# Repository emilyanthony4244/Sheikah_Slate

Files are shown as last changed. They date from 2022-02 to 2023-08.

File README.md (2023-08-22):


<!--
*** Thanks for checking out the Best-README-Template. If you have a suggestion
*** that would make this better, please fork the repo and create a pull request
*** or simply open an issue with the tag "enhancement".
*** Don't forget to give the project a star!
*** Thanks again! Now go create something AMAZING! :D
-->

<!-- PROJECT SHIELDS -->
<!--
*** I'm using markdown "reference style" links for readability.
*** Reference links are enclosed in brackets [ ] instead of parentheses ( ).
*** See the bottom of this document for the declaration of the reference variables
*** for contributors-url, forks-url, etc. This is an optional, concise syntax you may use.
*** https://www.markdownguide.org/basic-syntax/#reference-style-links
-->
[][contributors-url]
[][forks-url]
[][stars-url]
[][issues-url]
[][license-url]
[][linkedin-url]

<!-- PROJECT LOGO -->
<br />
<div align="center">
   


  <h3 align="center">Sheikah Slate Cosplay Project</h3>

  <p align="center">
    A functional, open source Sheikah Slate for cosplay or collectors.
<br />
    <a href="https://github.com/emilyanthony4244/Sheikah_Slate"><strong>Explore the slate »</strong></a>
<br />
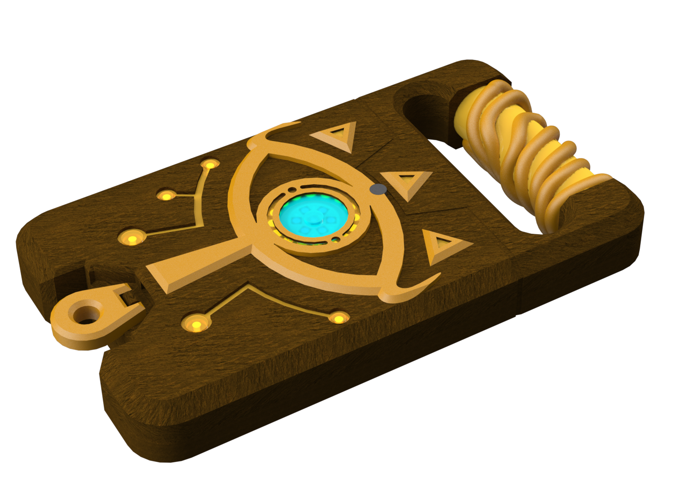
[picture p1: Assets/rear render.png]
rear render


<br />
    
<a href=" ">Demo Placeholder Link</a>
<br />

<a href="https://github.com/othneildrew/Best-README-Template/issues">Report Bug</a>

<a href="https://github.com/othneildrew/Best-README-Template/issues">Request Feature</a>
  </p>
</div>

<!-- TABLE OF CONTENTS -->
<details>
  <summary>Table of Contents</summary>
  <ol>
    <li>
      <a href="#about-the-project">About The Project</a>
      <ul>
        <li><a href="#built-with">Built With</a></li>
      </ul>
    </li>
    <li>
      <a href="#getting-started">Getting Started</a>
      <ul>
        <li><a href="#prerequisites">Prerequisites</a></li>
        <li><a href="#installation">Installation</a></li>
      </ul>
    </li>
    <li><a href="#usage">Usage</a></li>
    <li><a href="#roadmap">Roadmap</a></li>
    <li><a href="#contributing">Contributing</a></li>
    <li><a href="#license">License</a></li>
    <li><a href="#contact">Contact</a></li>
    <li><a href="#acknowledgments">Acknowledgments</a></li>
  </ol>
</details>

<!-- ABOUT THE PROJECT -->
## About The Project

In November 2021 I decided to tackle my next cosplay build – Nintendo’s Zelda Breath of the Wild’s Link, specifically his Royal Guardsman armor from the Champions Ballad DLC.

Sewing aside, the biggest part of the project proved to be the Sheikah slate. Initially I considered making a “dummy” prop, maybe with lights, but after doing some research I started down the Adafruit rabbit hole (thanks @ladyada) and opted to integrate a 7inch TFT touch screen, a small camera, a noisemaker, and various light sources.
A prototype was built with the following specifications and functions:
* ESP32 based microcontroller integrated with a custom PCB
* Light up orange and blue pieces along parts of the body
* Generate a “chirping” sound to mimic a Sheikah Sensor
* Simulate the “sleep” image, the sheikah logo shown above, when not in use
* Display basic menus for information 

Prototype Photos:

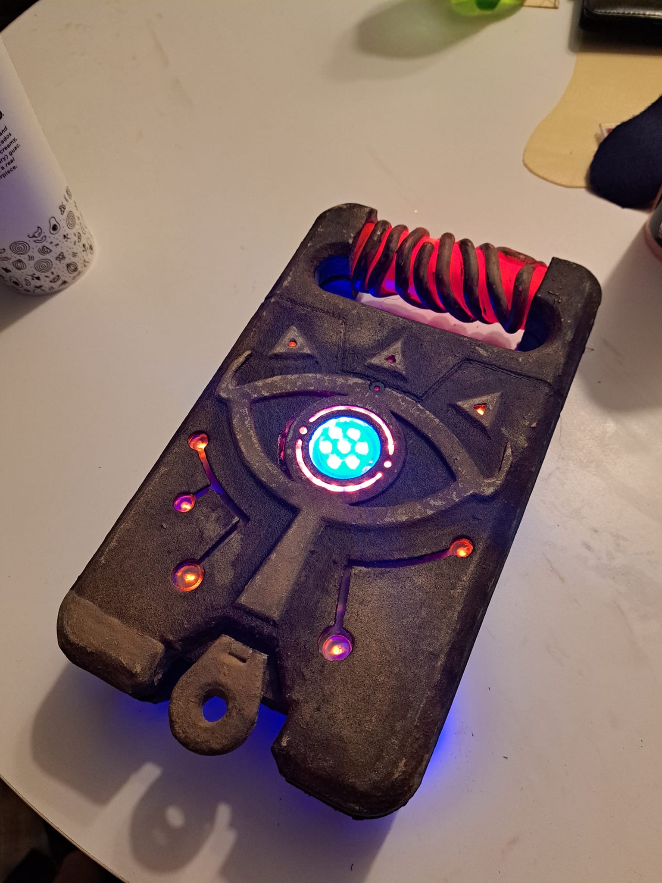
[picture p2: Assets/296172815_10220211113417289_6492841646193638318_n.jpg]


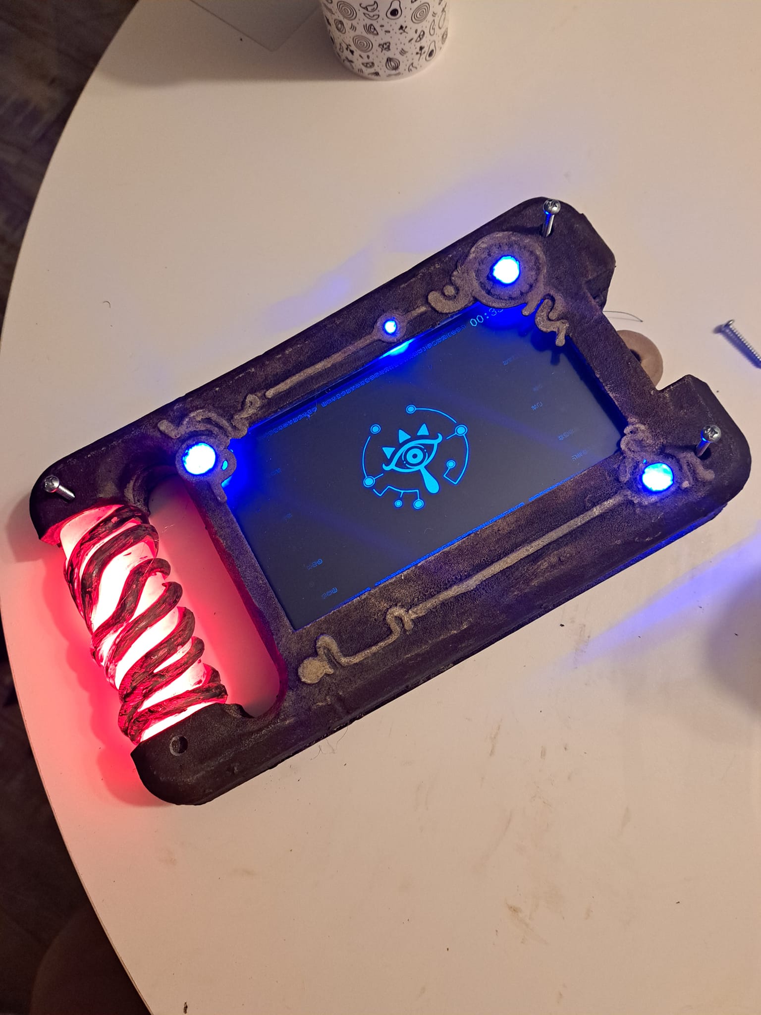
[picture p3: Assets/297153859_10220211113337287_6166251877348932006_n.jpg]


However, the prototype had a LONG way to go… so I went back to the drawing board and rolled up a V2.0. Improvements:
* On-board SD card integration to delete the SD shield
* Shrunk the board considerably (check out the photos!)
* Moved from DAC audio to a proper IIS solution
* Deleted all the bulb LEDs, moved to addressable everything for color coordination
* Integration of a TTL camera
* Board updates for noise shielding
* Proper GUI built using <a href=" https://github.com/ImpulseAdventure/GUIslice/wiki">
GUISlice Builder</a>

V1 vs V2 board size:

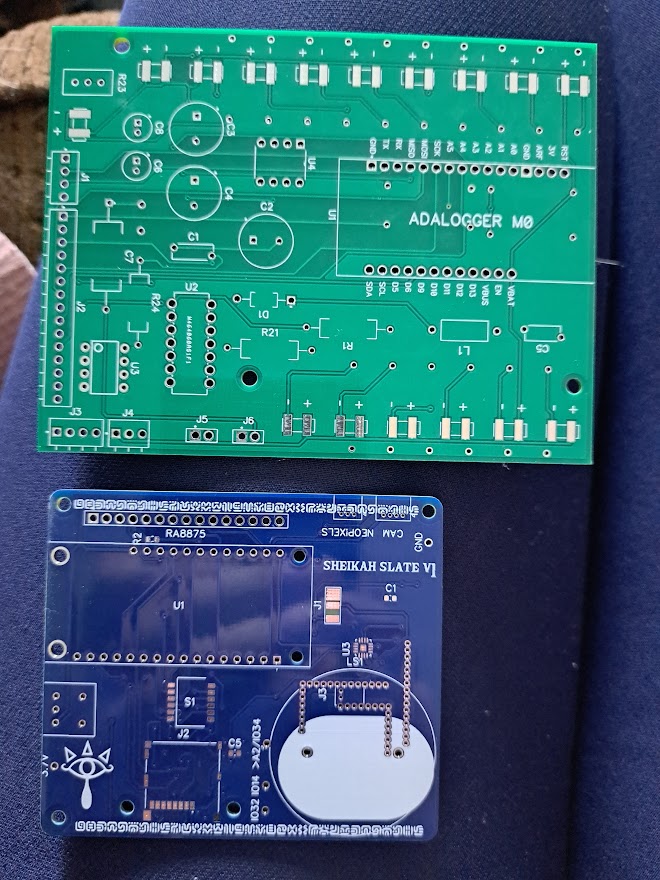
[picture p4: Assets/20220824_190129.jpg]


<p align="right">(<a href="#top">back to top</a>)</p>

### Built With

* [Arduino IDE](https://www.arduino.cc/en/software)
* [SOLIDWORKS Educational Edition 2020](https://www.solidworks.com)
* [Blender 2.90.1](https://www.blender.org/)
* [DipTrace PCB Layout](https://diptrace.com/diptrace-software/pcb-layout/)
* [DipTrace Schematic Capture](https://diptrace.com/diptrace-software/pcb-layout/)

<p align="right">(<a href="#top">back to top</a>)</p>

<!-- GETTING STARTED -->
## Getting Started

Building your own Sheikah Slate requires approximately $450, access to a 3D printer, some basic soldering skills, acrylic paints, and patience.

### Materials

Soldering Iron, a computer capable of running the Arduino IDE, glue, Philips head screwdriver, double sided tape.

<p align="center">AND</p>

FDM 3D printer capable of printing clear and solid color PLA filament with a minimum build volume of 275mm x 175mm x 25mm.

<p align="center">OR</p>

FDM 3D printer capable of printing solid PLA/ABS/PETG/etc AND an SLA printer capable of printing clear UV resin. I use an Anycubic Photon Mono X for SLA prints and a Creality CR10s Pro V2 for FDM prints.

<p align="center">OR</p>

Money to spend at www.HUBS.com or www.shapeways.com to outsource prints.

See the BOM in root directory for parts information. 3D print costs are estimates and will be higher if you outsource this print. PCBs can be ordered at various online vendors such as PCBway.com. I have extras and can sell you one for $12 + shipping. Otherwise, you can order from PCBway where I get a cut:

<a href="https://www.pcbway.com/project/shareproject/Sheikah_Slate_for_Cosplay_951a0c22.html">PCB from PCBWay</a>

### Installation

To Use the Adafruit Feather ESP32 v2 board in the Arduino IDE, you’ll need to follow the guide linked here: https://learn.adafruit.com/adafruit-esp32-feather-v2

All the necessary libraries “should” be in the Arduino folder above. Drop these in your local Arduino libraries folder for use. Open the SheikahSlate.ino file, select your board, and upload. If this doesn’t work, toss the library files in your default Arduino Libraries folder. Make sure you don’t have any conflicts in names or versions.

<p align="right">(<a href="#top">back to top</a>)</p>

<!-- HOW IT WORKS -->
## How it works

The Sheikah Slate combines the Adafruit RA8875 TFT driver board and Adafruit 7in 800x480 resistive touch TFT screen to simulate the in-game sheikah slate interface. The menus were created with GUIslice Builder (linked above) using the Adafruit GFX library. The SS V2 uses an ESP32 Pico microcontroller from Adafruit: the ESP32 Feather V2.

### SD Implementation

A SD card slot is provided on the board. This is a cloned circuit of the Adafruit MicroSD SPI or SDIO Breakout Board. The SD is SPI only.

<i> A note: RA8875 uses SPI mode 3 and SD uses SPI mode 0, so they are not compatible in the same SPI bus without isolation. This is why the 74HC125 chip is present. If you want to DIY you must populate this chip. </i>

In firmware, the SD CS is set to GPIO12.

### TFT Setup 

An example config file was used as a base and modified. This was renamed to sheikah_tft_config.h and included at the top of sheikahslate.ino. This can also be called in GUIslice_config.h.

Unfortunately the RA8875 is not compatible with TFT_eSPI from @Bodmer, so the AdafruitGFX and RA8875 libraries must be used.
The following items were modified from the base config:

<code>#define ADAGFX_PIN_CS       27    // Display chip select changed from 10 to 25
  #define ADAGFX_PIN_RST      23     // Display Reset is changed from 5 to 23
#define ADAGFX_PIN_SDCS     12    //SD CS</code>

For development, <code>#define DEBUG_ERR</code> was changed to 2. For release this will toggle to 0.

All optional features toggled to 1 for development; likely won’t need GPIO input in the end but who knows.

<code>#define GSLC_FEATURE_COMPOUND       1   // Compound elements (eg. XSelNum)
  #define GSLC_FEATURE_XTEXTBOX_EMBED 1   // XTextbox control with embedded color
  #define GSLC_FEATURE_INPUT          1   // Keyboard / GPIO input control</code>

SD enabled for obvious reasons:

<code>#define GSLC_SD_EN    1</code>

Pixel Buffer increased because I’m impatient

<code>#define GSLC_SD_BUFFPIXEL   85</code>

<i>A note: this pixel buffer is by default 8 bit. Even though the ESP32 can handle it, the display will not work if you increase this past 85 due to the way the SD library and GFX library reads files to the RA8875 LCD buffer. I may write a buffer for the buffer to send to the screen in larger chunks and am investigating how to speed this whole thing up. I am really concerned about the rate I can write images to the screen.</i>

### Camera

The Sheikah Slate features the Adafruit Miniature TTL Serial JPG camera. The camera captures 640x480 images and saves them to the SD in jpg format using the Adafruit VC0706 Camera library. The file names are formatted “IMAGExx.JPG” from 00 to 99.

When the Camera menu is selected, the user has the option to turn “flash” on and off. “Flash” is just lighting the NeoPixels on the back 100% brightness full white. This is just to help in low light; the VC0706 has auto brightness so there are no other settings in this menu.

Using the TJpg_Decoder library (also from @Bodmer), the jpgs are processed and resaved as 24bit BMP files and then displayed on the TFT. Jpeg files must be in 24bit format; luckily, the Adafruit TTL Serial Camera takes 24bit depth jpg images so it’s an easy conversion.

The Sheikah Slate does not and will never support streamed video to the display. Sorry.

### Audio

TODO

### Add features

There are 5 GPIO pins broken out in case you ever want to add something. Be aware that GPIO34, 36, and 39 are input only.

### NeoPixels

Finally, the slate has 11 button NeoPixels, a 16 pixel Ring, a Flora, and a 20 LED strip all from Adafruit. They’re all strung together and addressed on GPIO26. The order of the NeoPixels is as follows:

<table border="0" cellpadding="0" cellspacing="0" id="sheet0" class="sheet0 gridlines">
        <colgroup><col class="col0">
        <col class="col1">
        <col class="col2">
        <col class="col3">
        <col class="col4">
        <col class="col5">
        <col class="col6">
        <col class="col7">
        <col class="col8">
        <col class="col9">
        <col class="col10">
        <col class="col11">
        <col class="col12">
        <col class="col13">
        <col class="col14">
        <col class="col15">
        <col class="col16">
        <col class="col17">
        <col class="col18">
        <col class="col19">
        <col class="col20">
        <col class="col21">
        <col class="col22">
        <col class="col23">
        <col class="col24">
        <col class="col25">
        <col class="col26">
        <col class="col27">
        <col class="col28">
        <col class="col29">
        <col class="col30">
        <col class="col31">
        <col class="col32">
        <col class="col33">
        <col class="col34">
        <col class="col35">
        <col class="col36">
        <col class="col37">
        <col class="col38">
        <col class="col39">
        <col class="col40">
        <col class="col41">
        <col class="col42">
        <col class="col43">
        <col class="col44">
        <col class="col45">
        <col class="col46">
        <col class="col47">
        <col class="col48">
        <col class="col49">
        <col class="col50">
        <col class="col51">
        <col class="col52">
        <col class="col53">
        <col class="col54">
        <col class="col55">
        </colgroup><tbody>
          <tr class="row0">
            <td class="column0 style0 s">Position</td>
            <td class="column1 style0 n">0</td>
            <td class="column2 style0 n">1</td>
            <td class="column3 style0 n">2</td>
            <td class="column4 style0 n">3</td>
            <td class="column5 style0 n">4</td>
            <td class="column6 style0 n">5</td>
            <td class="column7 style0 n">6</td>
            <td class="column8 style0 n">7</td>
            <td class="column9 style0 n">8</td>
            <td class="column10 style0 n">9</td>
            <td class="column11 style0 n">10</td>
            <td class="column12 style0 n">11</td>
            <td class="column13 style0 n">12</td>
            <td class="column14 style0 n">13</td>
            <td class="column15 style0 n">14</td>
            <td class="column16 style0 n">15</td>
            <td class="column17 style0 n">16</td>
            <td class="column18 style0 n">17</td>
            <td class="column19 style0 n">18</td>
            <td class="column20 style0 n">19</td>
            <td class="column21 style0 n">20</td>
            <td class="column22 style0 n">21</td>
            <td class="column23 style0 n">22</td>
            <td class="column24 style0 n">23</td>
            <td class="column25 style0 n">24</td>
            <td class="column26 style0 n">25</td>
            <td class="column27 style0 n">26</td>
            <td class="column28 style0 n">27</td>
            <td class="column29 style0 n">28</td>
            <td class="column30 style0 n">29</td>
            <td class="column31 style0 n">30</td>
            <td class="column32 style0 n">31</td>
            <td class="column33 style0 n">32</td>
            <td class="column34 style0 n">33</td>
            <td class="column35 style0 n">34</td>
            <td class="column36 style0 n">35</td>
            <td class="column37 style0 n">36</td>
            <td class="column38 style0 n">37</td>
            <td class="column39 style0 n">38</td>
            <td class="column40 style0 n">39</td>
            <td class="column41 style0 n">40</td>
            <td class="column42 style0 n">41</td>
            <td class="column43 style0 n">42</td>
            <td class="column44 style0 n">43</td>
            <td class="column45 style0 n">44</td>
            <td class="column46 style0 n">45</td>
            <td class="column47 style0 n">46</td>
            <td class="column48 style0 n">47</td>
            <td class="column49 style0 n">48</td>
            <td class="column50 style0 n">49</td>
            <td class="column51 style0 n">50</td>
            <td class="column52 style0 n">51</td>
            <td class="column53 style0 n">52</td>
            <td class="column54 style0 n">53</td>
            <td class="column55 style0 n">54</td>
          </tr>
          <tr class="row1">
            <td class="column0 style0 s">Description</td>
            <td class="column1 style1 s style1" colspan="3">Lashes</td>
            <td class="column4 style1 s style1" colspan="5">Dots Back</td>
            <td class="column9 style1 s style1" colspan="16">Ring</td>
            <td class="column25 style1 s style1" colspan="7">Flora</td>
            <td class="column32 style1 s style1" colspan="4">Dots Front</td>
            <td class="column36 style1 s style1" colspan="20">Strip Handle</td>
          </tr>
          <tr class="row2">
            <td class="column0 style0 s">Default Color</td>
            <td class="column1 style1 s style1" colspan="24">Amber</td>
            <td class="column25 style1 s style1" colspan="11">Blue</td>
            <td class="column36 style1 s style1" colspan="20">Amber</td>
          </tr>
          <tr class="row3">
            <td class="column0 style0 s">Default Brightness</td>
            <td class="column1 style2 n style2" colspan="55">30%</td>
          </tr>
          <tr class="row4">
            <td class="column0 style0 s">Low Battery Color</td>
            <td class="column1 style1 s style1" colspan="8">Amber</td>
            <td class="column9 style1 s style1" colspan="16">Red</td>
            <td class="column25 style1 s style1" colspan="11">Blue</td>
            <td class="column36 style1 s style1" colspan="20">Amber</td>
          </tr>
          <tr class="row5">
            <td class="column0 style0 s">Low Battery Brightness</td>
            <td class="column1 style2 n style2" colspan="8">10%</td>
            <td class="column9 style2 n style2" colspan="16">40%</td>
            <td class="column25 style2 n style2" colspan="31">10%</td>
          </tr>
          <tr class="row6">
            <td class="column0 style0 s">Idle Color</td>
            <td class="column1 style1 s style1" colspan="24">Amber</td>
            <td class="column25 style1 s style1" colspan="11">Blue</td>
            <td class="column36 style1 s style1" colspan="20">Amber</td>
          </tr>
          <tr class="row7">
            <td class="column0 style0 s">Idle Brightness</td>
            <td class="column1 style1 s style1" colspan="55">Breathe 1% to 25%</td>
          </tr>
          <tr class="row8">
            <td class="column0 style0 s">Photo Menu Color</td>
            <td class="column1 style1 s style1" colspan="35">White</td>
            <td class="column36 style1 s style1" colspan="20">Amber</td>
          </tr>
          <tr class="row9">
            <td class="column0 style0 s">Photo Menu Brightness</td>
            <td class="column1 style2 s style2" colspan="35">toggle 0% or 100%</td>
            <td class="column36 style2 n style2" colspan="20">30%</td>
          </tr>
        </tbody>
    </table>

### A note regarding memory, core usage, etc

The libraries required for this project built with an entirely empty sketch took uses about 0.3MB of flash memory. Be wise about adding screens with the GUISlice Builder and store all images on the SD. Don’t try to be sly and write to FLASH.

Currently I am not fiddling with the default core assignments in the Arduino IDE for the ESP32. I am considering offloading the SD buffer to LCD Buffer to core 1 as well as the jpg to bmp file conversion. I’d love to use both cores of the ESP32, but just one can do everything I’d like it to do.

TJpg_Decoder has an example where it renders a Jpeg file that is stored in an array within Flash memory. The Jpeg decoding is done by one processor core 0 and the rendering to TFT by processor 1. I may be able to reformat this to use the 2MB of PSRAM available.
<!-- USAGE EXAMPLES -->
## Usage

Placeholder for menu items and features

<p align="right">(<a href="#top">back to top</a>)</p>

<!-- ROADMAP -->
## Roadmap

- [x] Add Readme
- [x] Add back to top links
- [x] Add Installation instructions
- [WIP] Add Arduino Firmware
- [ ] Add Menu Images in Usage Section
- [ ] Film Demo and take pretty photos

<p align="right">(<a href="#top">back to top</a>)</p>

<!-- CONTRIBUTING -->
## Contributing

Contributions are what make the open source community such an amazing place to learn, inspire, and create. Any contributions you make are **greatly appreciated**.

If you have a suggestion that would make this better, please fork the repo and create a pull request. You can also simply open an issue with the tag "enhancement".
Don't forget to give the project a star! Thanks again!

1. Fork the Project
2. Create your Feature Branch (`git checkout -b feature/AmazingFeature`)
3. Commit your Changes (`git commit -m 'Add some AmazingFeature'`)
4. Push to the Branch (`git push origin feature/AmazingFeature`)
5. Open a Pull Request

<p align="right">(<a href="#top">back to top</a>)</p>

<!-- LICENSE -->
## License

See `LICENSE.txt` for information.

<p align="right">(<a href="#top">back to top</a>)</p>

<!-- CONTACT -->
## Contact

Emily Anthony - [@thelegendofemily](https://instagram.com/thelegendofemily) 

Project Link: [https://github.com/emilyanthony4244/Sheikah_Slate](https://github.com/emilyanthony4244/Sheikah_Slate)

<p align="right">(<a href="#top">back to top</a>)</p>

<!-- ACKNOWLEDGMENTS -->
## Acknowledgments

Use this space to list resources you find helpful and would like to give credit to. I've included a few of my favorites to kick things off!

* [OthNealDrew’s Readme template]( https://github.com/othneildrew/Best-README-Template)
<p align="right">(<a href="#top">back to top</a>)</p>

<!-- MARKDOWN LINKS & IMAGES -->
<!-- https://www.markdownguide.org/basic-syntax/#reference-style-links -->
[contributors-shield]: https://img.shields.io/github/contributors/emilyanthony4244/Sheikah_Slate.svg?style=for-the-badge
[contributors-url]: https://github.com/emilyanthony4244/Sheikah_Slate/graphs/contributors
[forks-shield]: https://img.shields.io/github/forks/emilyanthony4244/Sheikah_Slate.svg?style=for-the-badge
[forks-url]: https://github.com/emilyanthony4244/Sheikah_Slate/network/members
[stars-shield]: https://img.shields.io/github/stars/emilyanthony4244/Sheikah_Slate.svg?style=for-the-badge
[stars-url]: https://github.com/emilyanthony4244/Sheikah_Slate/stargazers
[issues-shield]: https://img.shields.io/github/issues/emilyanthony4244/Sheikah_Slate.svg?style=for-the-badge
[issues-url]: https://github.com/emilyanthony4244/Sheikah_Slate/issues
[license-shield]: https://img.shields.io/github/license/emilyanthony4244/Sheikah_Slate.svg?style=for-the-badge
[license-url]: https://github.com/emilyanthony4244/Sheikah_Slate/blob/main/LICENSE
[linkedin-shield]: https://img.shields.io/badge/-LinkedIn-black.svg?style=for-the-badge&logo=linkedin&colorB=555
[linkedin-url]: https://linkedin.com/in/emilyanthony

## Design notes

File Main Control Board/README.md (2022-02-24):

# Main Control Board

Please review open issues regarding the main control board prior to ordering PCBs.

## Renders

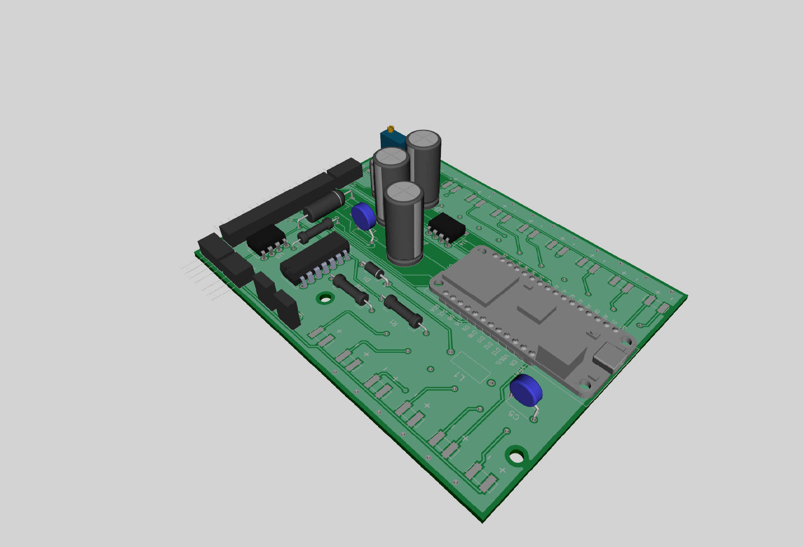
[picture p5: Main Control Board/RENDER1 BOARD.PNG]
Top Render


Top Render. Note: Capacitors may not be rendered correctly. Some components are missing.

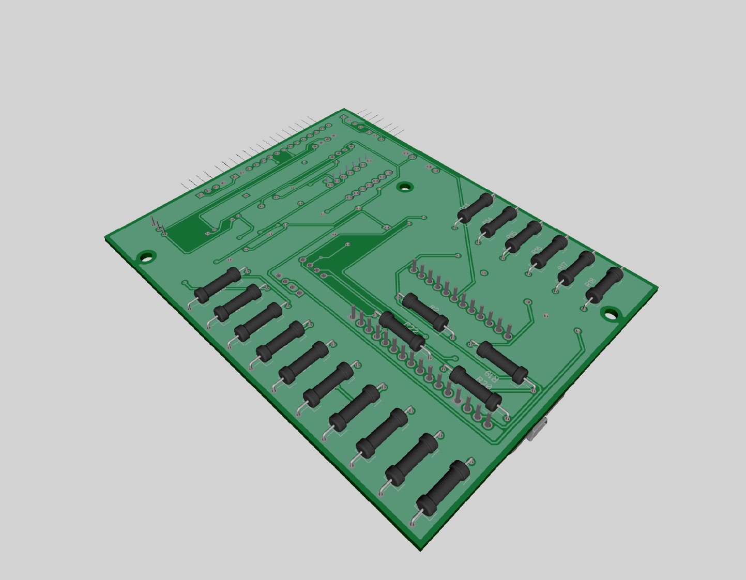
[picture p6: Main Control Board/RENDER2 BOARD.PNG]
Bottom Render

Bottom Render.

## Basic Information

2 layer PCB, 1.6mm thickness. 83.8 x 108 mm. Ordered on www.pcbway.com.

Designed in Diptrace, referencing several helpful guides, which I’ve included in the <a href=”##References”>References</a> section.

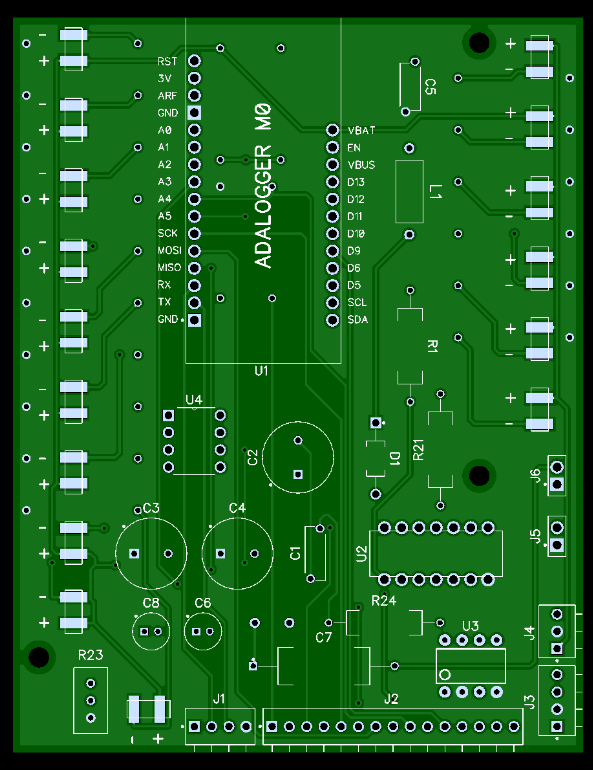
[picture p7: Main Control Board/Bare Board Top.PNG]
Top Bare Board
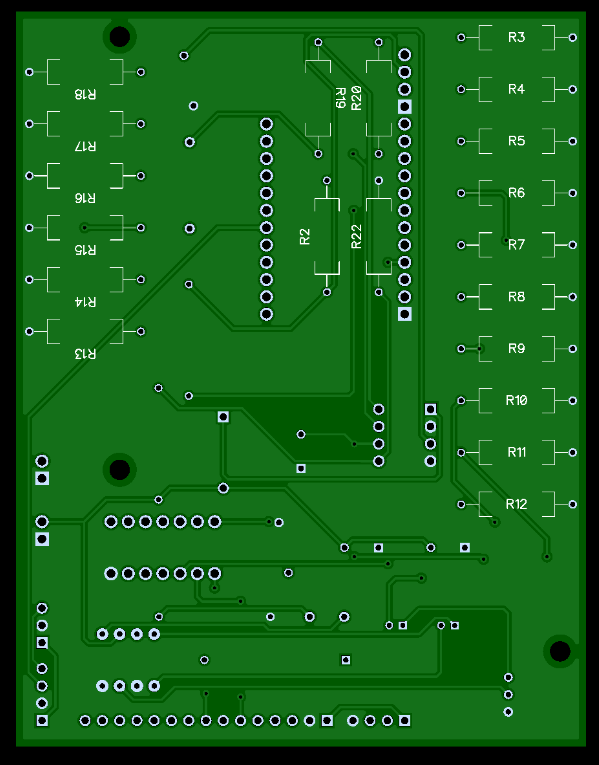
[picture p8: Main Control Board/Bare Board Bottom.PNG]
Top Bare Board


## Schematics

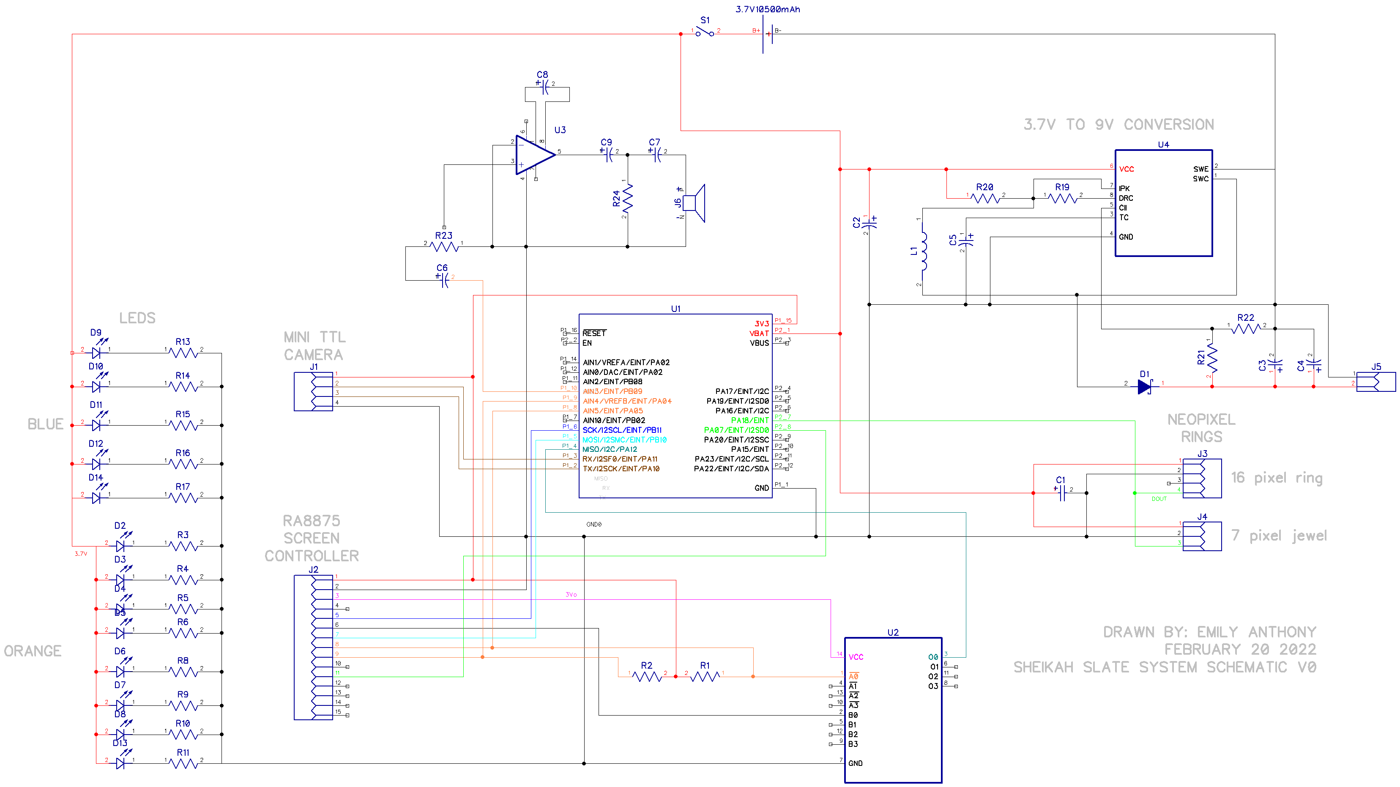
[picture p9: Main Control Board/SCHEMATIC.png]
SCHEMATICS


## References

* [Adafruit Feather Adalogger M0 Guide]( https://learn.adafruit.com/adafruit-feather-m0-adalogger/overview)
* [Adafruit Neopixel Uberguide](https://learn.adafruit.com/adafruit-neopixel-uberguide/the-magic-of-neopixels)
* [Adafruit TTL Serial Camera Guide](https://learn.adafruit.com/ttl-serial-camera)
* [Adafruit RA8875 Touch Display Driver Board Guide](https://learn.adafruit.com/ra8875-touch-display-driver-board)
* [Adafruit Forums for 74HC125 tri-state buffer chip]( https://forums.adafruit.com/viewtopic.php?f=47&t=60533&start=60#p323604)
* [Arduino Audio Music Player – Circuit Digest]( https://circuitdigest.com/microcontroller-projects/arduino-audio-music-player)

<!-- CONTACT -->
## Contact

Emily Anthony - [@thelegendofemily](https://instagram.com/thelegendofemily) 

Project Link: [https://github.com/emilyanthony4244/Sheikah_Slate](https://github.com/emilyanthony4244/Sheikah_Slate)

<p align="right">(<a href="#top">back to top</a>)</p>

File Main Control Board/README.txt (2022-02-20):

# Main Control Board

## Renders

Top Render
Top Render. Note: Capacitors may not be rendered correctly. Some components are missing.

Bottom Render
Bottom Render.

## Basic Information

2 layer PCB, 1.6mm thickness. 83.8 x 108 mm. Ordered on www.pcbway.com.

Designed in Diptrace, referencing several helpful guides, which I’ve included in the <a href=”##References”>References</a> section.

Top Bare BoardTop Bare Board

##Schematics

To Be Uploaded

##References
* [Adafruit Feather Adalogger M0 Guide]( https://learn.adafruit.com/adafruit-feather-m0-adalogger/overview)
* [Adafruit Neopixel Uberguide](https://learn.adafruit.com/adafruit-neopixel-uberguide/the-magic-of-neopixels)
* [Adafruit TTL Serial Camera Guide](https://learn.adafruit.com/ttl-serial-camera)
* [Adafruit RA8875 Touch Display Driver Board Guide](https://learn.adafruit.com/ra8875-touch-display-driver-board)
* [Adafruit Forums for 74HC125 tri-state buffer chip]( https://forums.adafruit.com/viewtopic.php?f=47&t=60533&start=45#p323058)
* [Simple Audio Player – Arduino Forums]( https://docs.arduino.cc/tutorials/generic/simple-audio-player)

<!-- CONTACT -->
## Contact

Emily Anthony - [@thelegendofemily](https://instagram.com/thelegendofemily) 

Project Link: [https://github.com/emilyanthony4244/Sheikah_Slate](https://github.com/emilyanthony4244/Sheikah_Slate)

<p align="right">(<a href="#top">back to top</a>)</p>

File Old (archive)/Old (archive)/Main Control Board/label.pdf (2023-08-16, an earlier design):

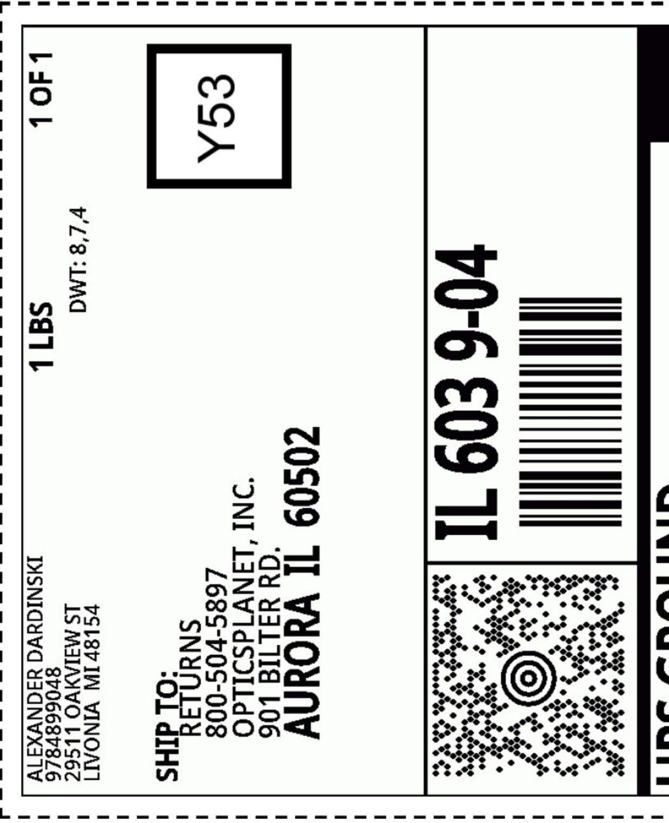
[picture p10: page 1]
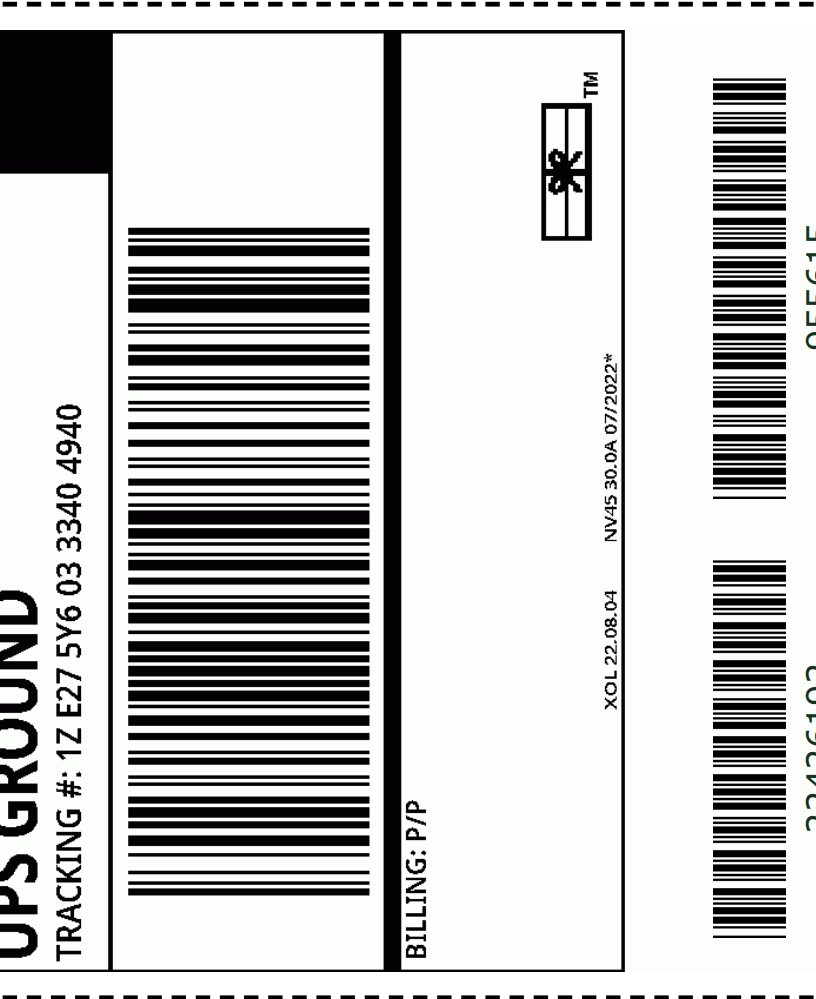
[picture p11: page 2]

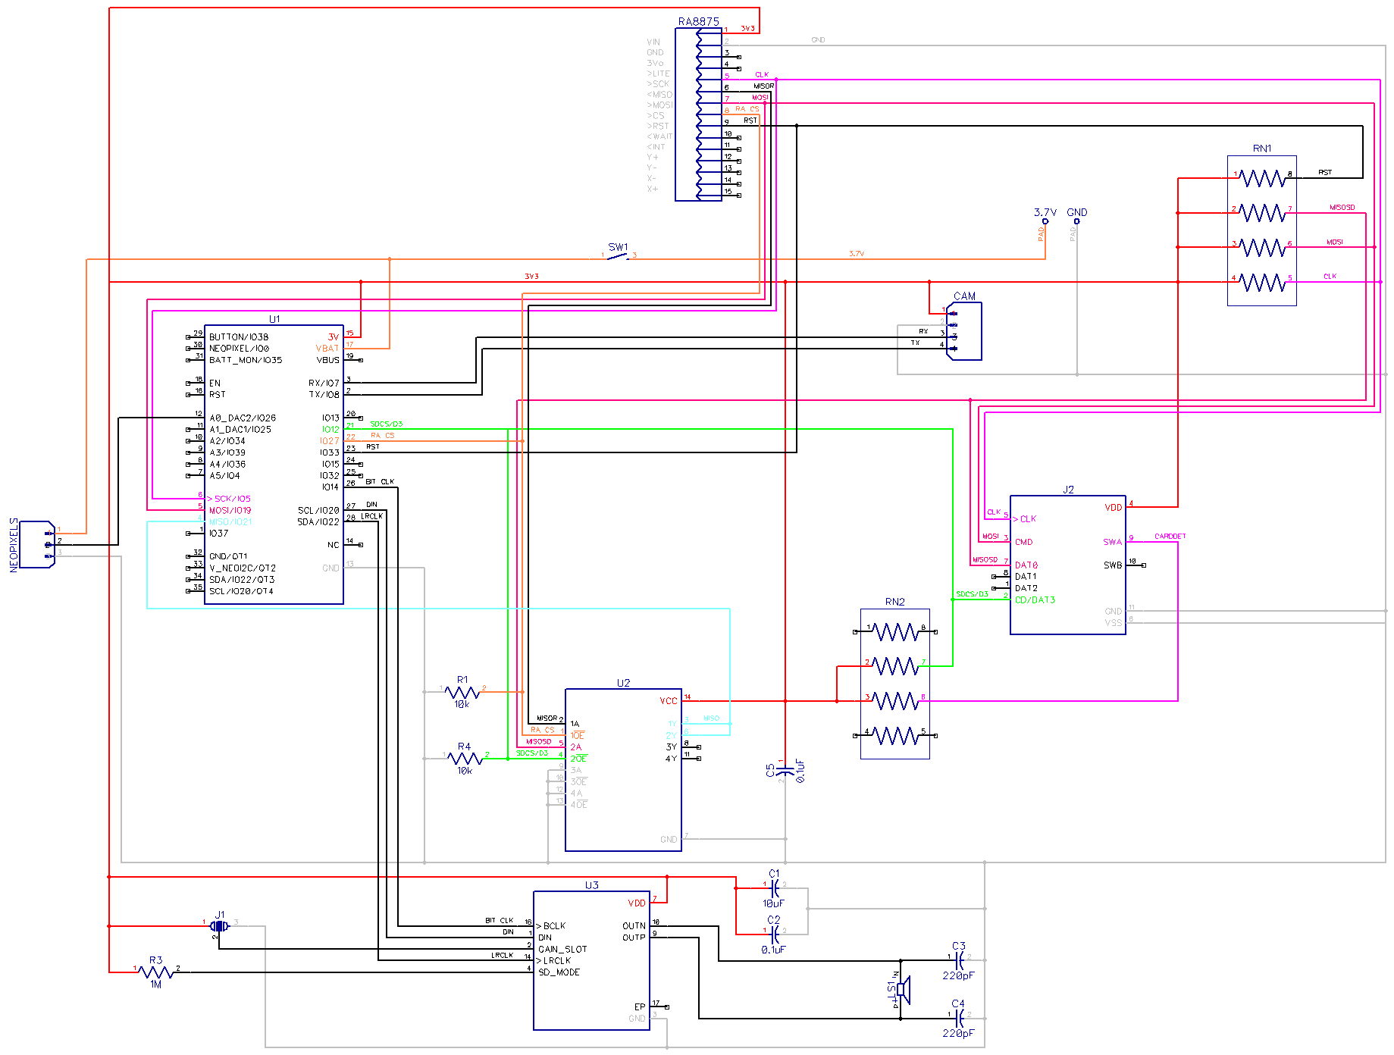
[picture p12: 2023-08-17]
PCB Design Files/Schematic v2.png

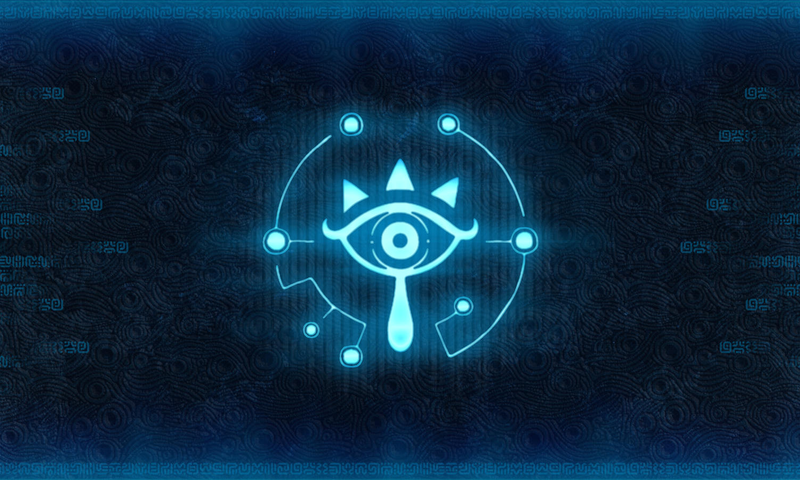
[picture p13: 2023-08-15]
Assets/4k_botw_sheikah_slate_by_si7vervvolf_dbxczga-fullview.bmp

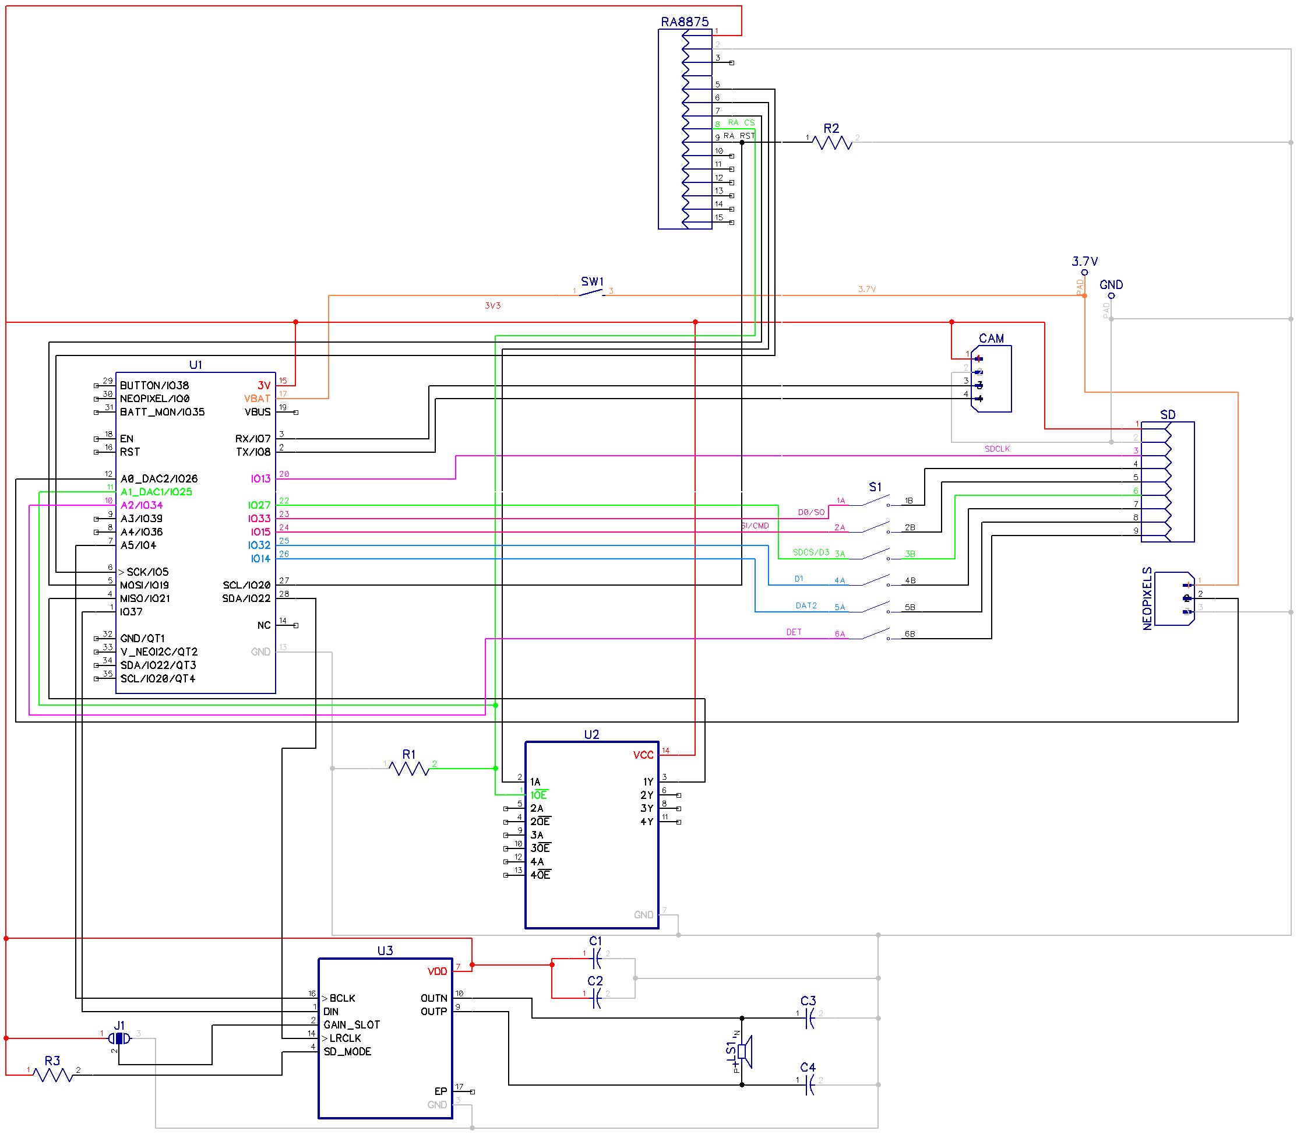
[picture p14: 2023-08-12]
Assets/slatev1.png

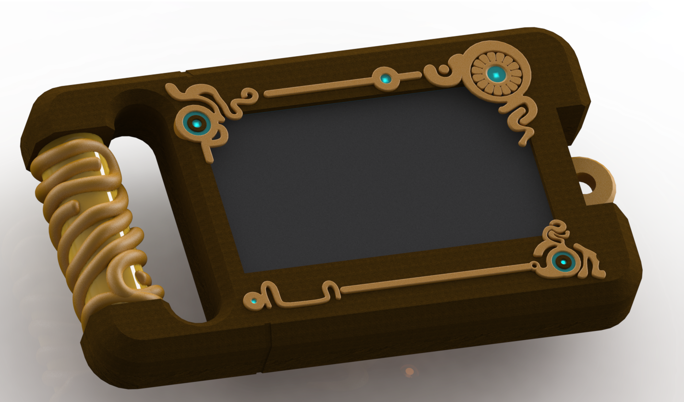
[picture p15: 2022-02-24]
Assets/Front render.png

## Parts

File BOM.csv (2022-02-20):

Number | Item | Manufacturer | PN | Qty | Unit Cost | Total Cost
1 | 99461A941 Thread Forming Screw | MCMASTER | 99461A941 | 7 | $0.15 | $1.04
2 | 3.7V Battery | Adafruit | 5035 | 1 | $29.95 | $29.95
3 | Adafruit TTL mini camera | Adafruit | 1386 | 1 | $35.95 | $35.95
4 | Assembled PCB | PCBWAY |  | 1 | $59.84 | $59.84
5 | Back Body | FDM 3DP |  | 1 | $50.00 | $50.00
6 | Bottom Left Blue LED Holder | SLA 3DP |  | 1 | $5.00 | $5.00
7 | Bottom Middle Blue LED Holder | SLA 3DP |  | 1 | $5.00 | $5.00
8 | Bottom Right Blue LED Holder | SLA 3DP |  | 1 | $5.00 | $5.00
9 | Bottom Right Disk | FDM 3DP |  | 1 | $5.00 | $5.00
10 | Eyelash Orange LED1 | SLA 3DP |  | 1 | $5.00 | $5.00
11 | Eyelash Orange LED2 | SLA 3DP |  | 1 | $5.00 | $5.00
12 | Eyelash Orange LED3 | SLA 3DP |  | 1 | $5.00 | $5.00
13 | Feather M0 Adalogger | Adafruit | in PCB | 0 | $- | $-
14 | Front Body | SLA 3DP |  | 1 | $50.00 | $50.00
15 | Handle Tube | SLA 3DP |  | 1 | $20.00 | $20.00
16 | TFT DISPLAY - 800X480 WITH TOUCH | Adafruit | 2354 | 1 | $47.50 | $47.50
17 | HLMP-QB00-S0000 Blue LED | Broadcom | HLMP-QB00-S0000 | 5 | $1.25 | $6.25
18 | Inner Neopixel Ring Holder | SLA 3DP |  | 1 | $5.00 | $5.00
19 | Left Orange LED Panel | SLA 3DP |  | 1 | $5.00 | $5.00
20 | NeoPixelRing16 | Adafruit | 1463 | 1 | $9.95 | $9.95
21 | Outer Neopixel Ring Holder | SLA 3DP |  | 1 | $5.00 | $5.00
22 | Right Orange LED Panel | SLA 3DP |  | 1 | $10.00 | $10.00
23 | SLR-343DC3F Orange LED | rohm | SLR-343DC3F | 8 | $0.28 | $2.24
24 | Top Left Blue LED Holder | SLA 3DP |  | 1 | $5.00 | $5.00
25 | Top Left Disk | SLA 3DP |  | 1 | $5.00 | $5.00
26 | Top Right Blue LED Holder | SLA 3DP |  | 1 | $5.00 | $5.00
27 | Wire Red 24 GA | digikey |  | 1 | $5.00 | $5.00
28 | Wire Black 24 GA | digikey |  | 1 | $5.00 | $5.00
29 | Wire White 24 GA | digikey |  | 1 | $5.00 | $5.00
30 | Wire Green 24 GA | digikey |  | 1 | $5.00 | $5.00
31 | Wire Yellow 24 GA | digikey |  | 1 | $5.00 | $5.00
32 | Wire Orange 24 GA | digikey |  | 1 | $5.00 | $5.00
33 | Wire Purple 24 GA | digikey |  | 1 | $5.00 | $5.00
34 | Speaker | Adafruit | 1898 | 1 | $1.85 | $1.85
35 | NeoPixel Jewel | Adafruit | 2226 | 1 | $5.95 | $5.95
36 | EL Panel | Adafruit | 625 | 1 | $13.95 | $13.95
37 | EL Panel Inverter | CoolLight | CL-IPTC-9v-3-7FT | 1 | $6.25 | $6.25
 |  |  |  |  | Total | $450.72

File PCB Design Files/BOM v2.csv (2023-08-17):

# | Description | Name | Value | Manufacturer | Quantity | RefDes | Description
1 |  | CAP_0603_N | 10uF |  | 5 | C1, C2, C3, C4, C5
2 | N/A | 530480410 |  | Hirose | 1 | CAM | N/A
3 |  | PPTC051LFBN-RC | 25 >34 >39 >36 4 | Sullins | 1 | GPIOBREAKOUT
4 |  | Solder_JMP_4V |  |  | 1 | J1
5 | Conn Memory Card RCP 8 POS 1.1mm Solder RA SMD 0.5A/Contact T/R | 2201778-1 |  |  | 1 | J2 | Conn Memory Card RCP 8 POS 1.1mm Solder RA SMD 0.5A/Contact T/R
6 | Conn Shrouded Header (4 Sides) HDR 2 POS 1.25mm Solder RA Side Entry Thru-Hole PicoBlade™ Tray | 530480210 |  |  | 1 | J3 | Conn Shrouded Header (4 Sides) HDR 2 POS 1.25mm Solder RA Side Entry Thru-Hole PicoBlade™ Tray
7 | Conn Shrouded Header (4 Sides) HDR 3 POS 1.25mm Solder RA Side Entry Thru-Hole PicoBlade™ Tray | 530480310 |  | Sullins | 1 | NEOPIXELS | Conn Shrouded Header (4 Sides) HDR 3 POS 1.25mm Solder RA Side Entry Thru-Hole PicoBlade™ Tray
8 |  | RES_0603_M | 10k |  | 3 | R1, R3, R4
9 |  | PPTC151LFBN-RC |  | Sullins | 1 | RA8875
10 | 47k Ohm ±0.5% 100mW Power Per Element Isolated 4 Resistor Network/Array ±50ppm/°C 1206 (3216 Metric), Convex, Long Side Terminals | ACASA470224702P100 |  |  | 2 | RN1, RN2 | 47k Ohm ±0.5% 100mW Power Per Element Isolated 4 Resistor Network/Array ±50ppm/°C 1206 (3216 Metric), Convex, Long Side Terminals
11 |  | AS11CH |  |  | 1 | SW1
12 | ESP32 802.11 Wireless LAN Development Board | DS05-127-2-06BK-SMT-TR | ESP32 FEATHER V2 | ADAFRUIT | 1 | U1 | ESP32 802.11 Wireless LAN Development Board
13 | 4-ch, 2-V to 6-V buffers with 3-state outputs | SN74HC125DR |  |  | 1 | U2 | 4-ch, 2-V to 6-V buffers with 3-state outputs
14 |  | MAX98357AETE+T |  |  | 1 | U3

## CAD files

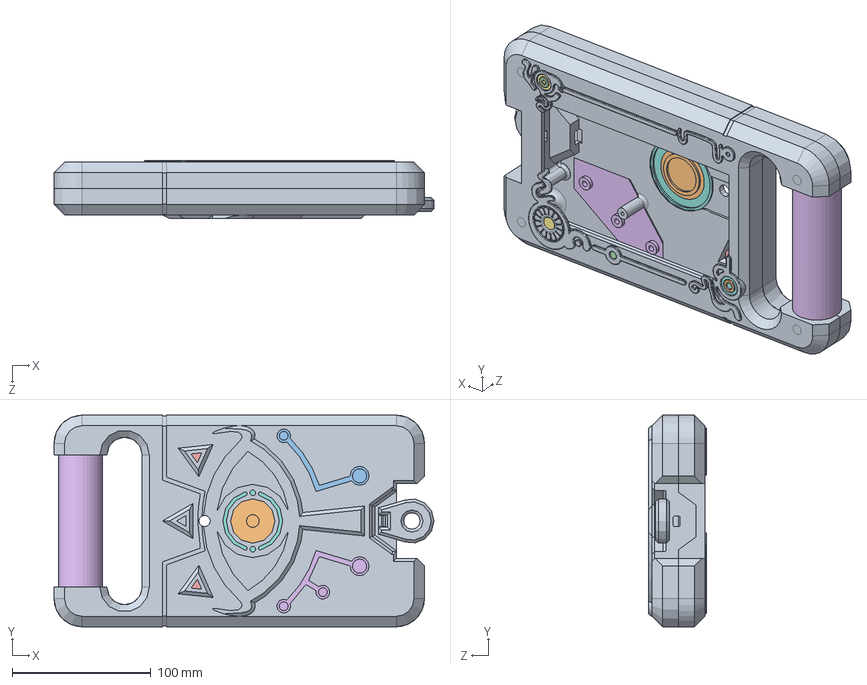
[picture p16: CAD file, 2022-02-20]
SOLIDWORKS/Sheikah Slate Body Converted Assembly.SLDASM
273.5 x 152.4 x 41.9 mm
Front Body
Bottom Right Disk
Top Right Blue LED Holder
Top Left Disk
Eyelash Orange LED1
Handle Tube
Top Left Blue LED Holder
Bottom Right Blue LED Holder
Eyelash Orange LED2
Inner Neopixel Ring Holder
Left Orange LED Panel
Bottom Middle Blue LED Holder
Eyelash Orange LED3
Right Orange LED Panel
Bottom Left Blue LED Holder
Outer Neopixel Ring Holder
Back Body

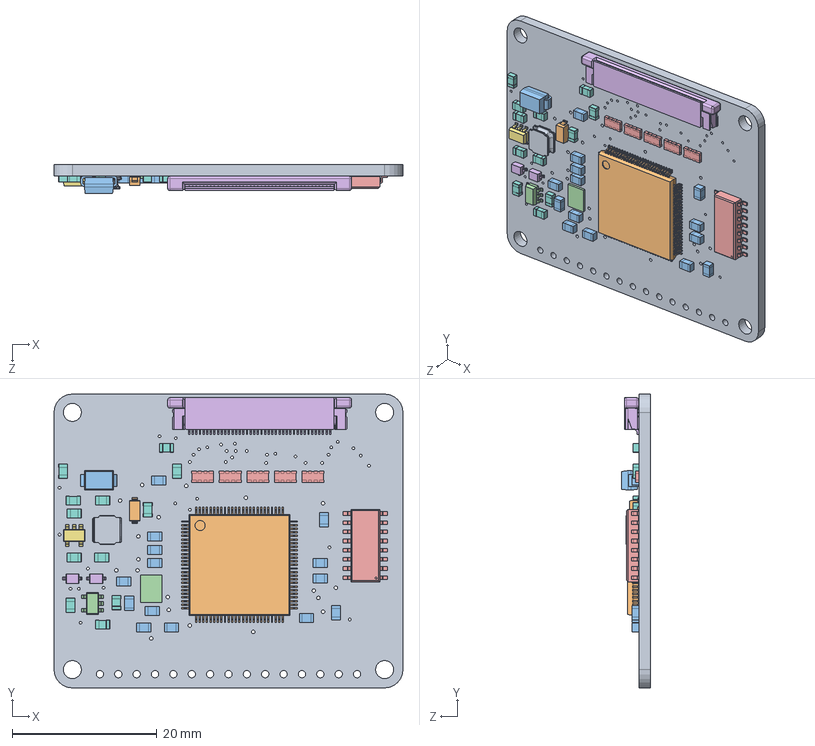
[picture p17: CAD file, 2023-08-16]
SOLIDWORKS/sheikah slate/Adafruit RA8875 TFT Breakout.SLDASM
48.3 x 40.6 x 4.01 mm
Board.step
RA8875.step
10K.step x 14
20MHz.step
33.step x 5
40PINFPCM4-1734839-0.step
FAN5333BSX.step
3Ω.step x 12
6.8uH large inductor.step
MBR0540.step
MM3Z24VT1G.step
MIC5225-3.3v.step
74HC4050.step
1N4148.step x 2

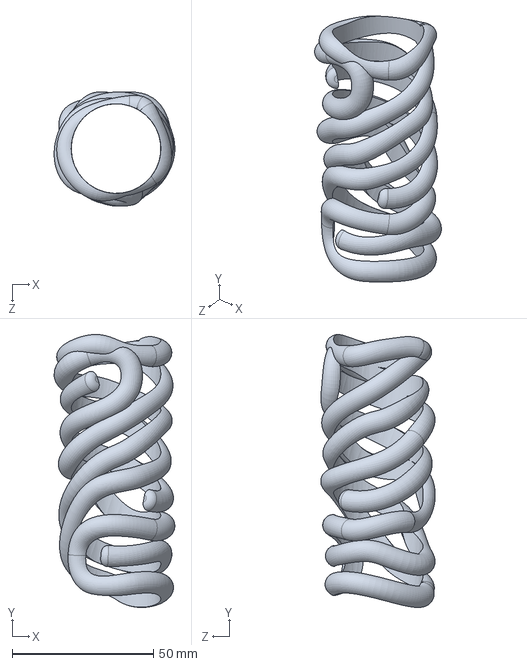
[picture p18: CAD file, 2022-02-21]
SOLIDWORKS/sheikah slate swirly bits.SLDPRT
42.8 x 96.7 x 40.6 mm

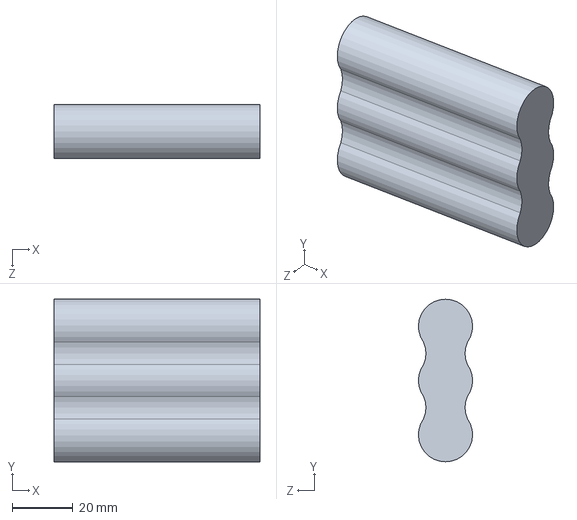
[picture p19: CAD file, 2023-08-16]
SOLIDWORKS/sheikah slate/adafruit 5035 battery.SLDPRT
67.6 x 53.3 x 17.8 mm

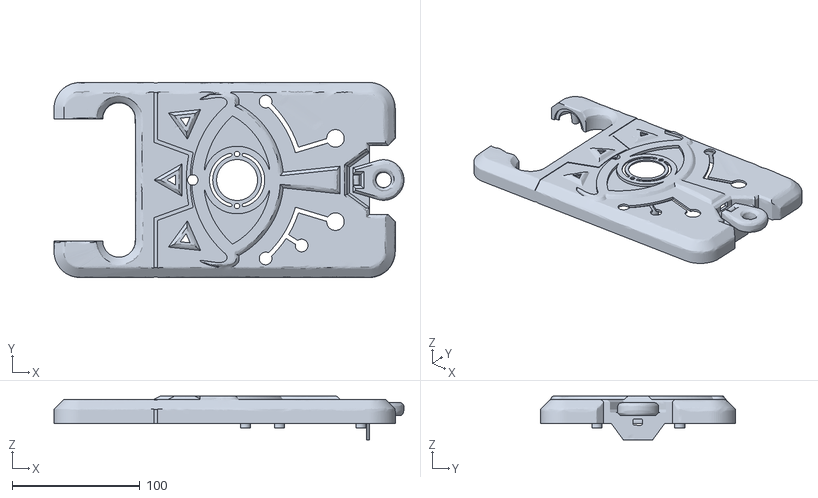
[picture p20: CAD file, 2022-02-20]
STLs/Back Body Sculpted.stl
273.5 x 152.4 x 34.3

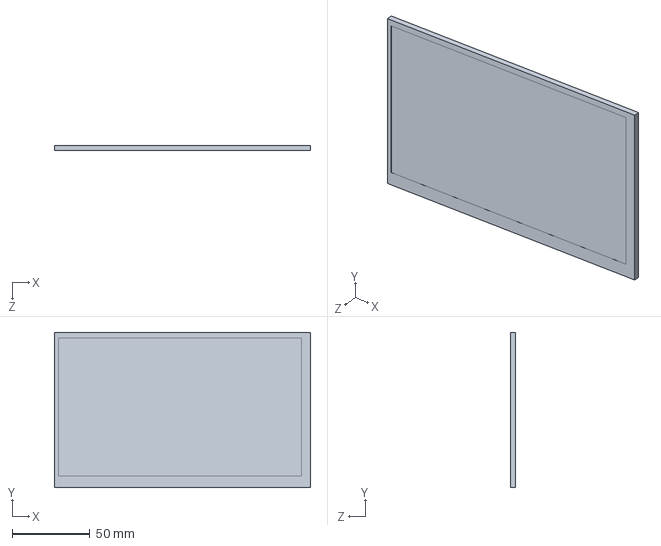
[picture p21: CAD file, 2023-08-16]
SOLIDWORKS/sheikah slate/HDMI 7po adafruit.SLDPRT
164.9 x 100.0 x 3.45 mm

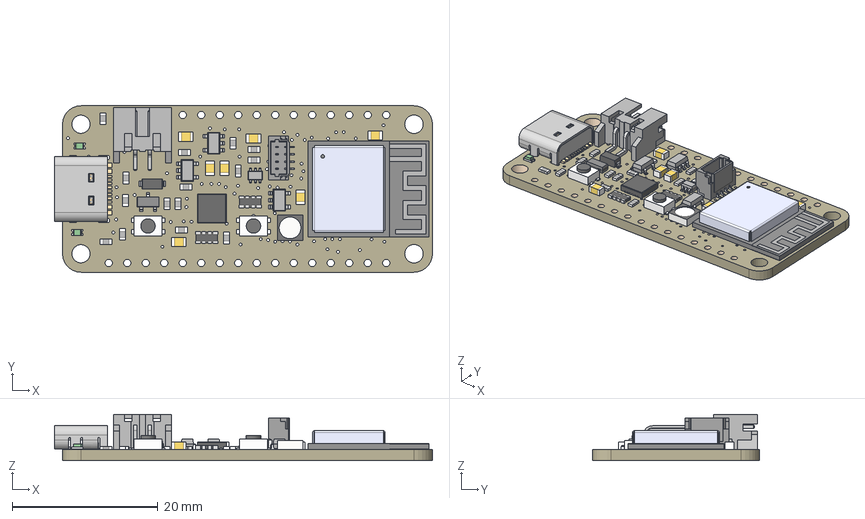
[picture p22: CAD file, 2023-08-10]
CAD/5400 ESP32 Feather V2.step
51.9 x 22.9 x 6.37 mm
Board
10uF x 7
AP2112-3.3 x 2
MBR540
JSTPH
MCP73831T-2ACI/OT
RED x 2
1uF x 15
KMR2 x 2
DMG3415U
47K x 2
ESP32-PICO-MINI-02MINI
WS2812B3535
STEMMA_I2C_QTRA
TPB1,27 x 2
USB Type C
CP2102N-24
DUAL NPN

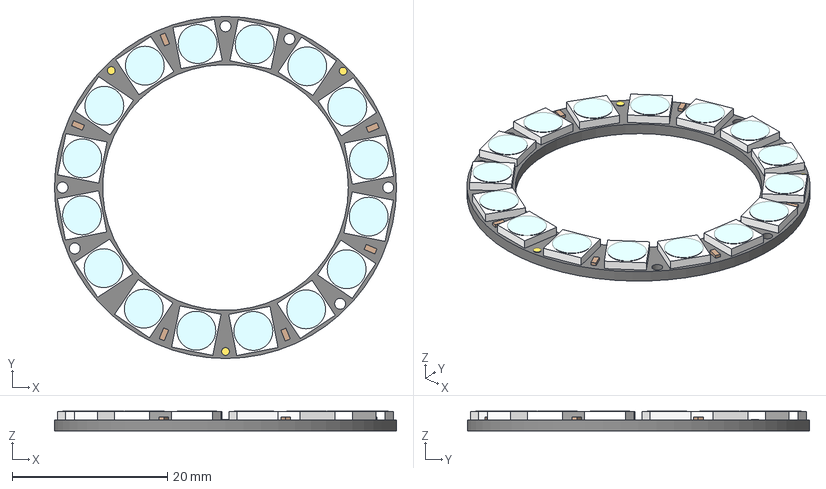
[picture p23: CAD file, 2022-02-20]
SOLIDWORKS/sheikah slate/NeoPixelRing16.step
44.0 x 44.0 x 2.55 mm

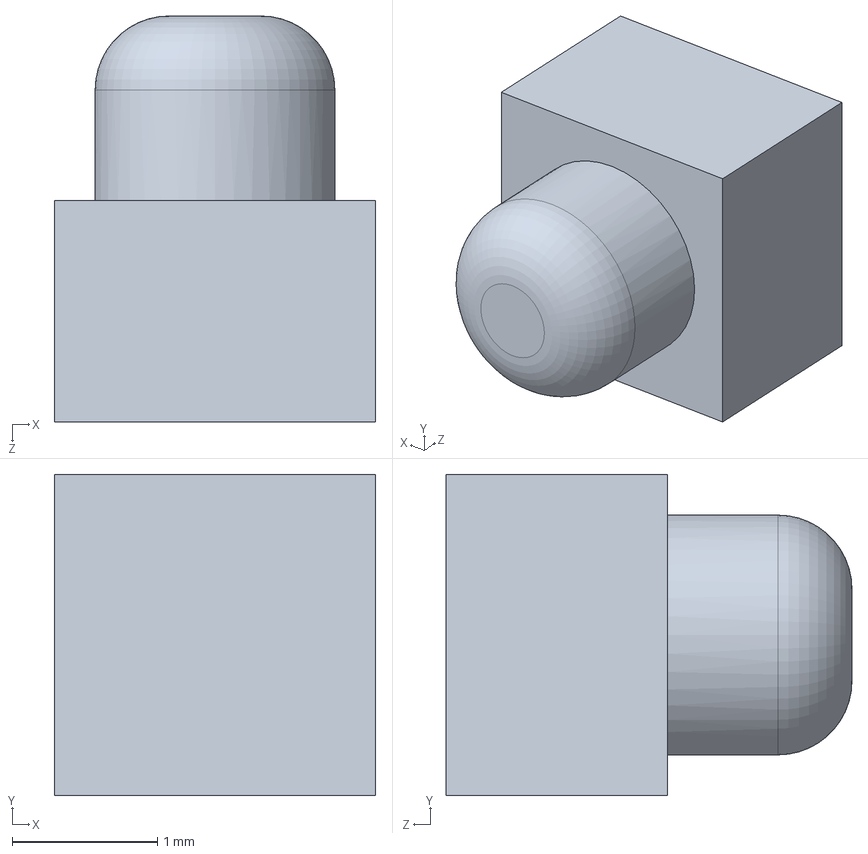
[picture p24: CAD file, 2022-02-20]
SOLIDWORKS/sheikah slate/HLMP-QB00-S0000.SLDPRT
2.21 x 2.21 x 2.79 mm

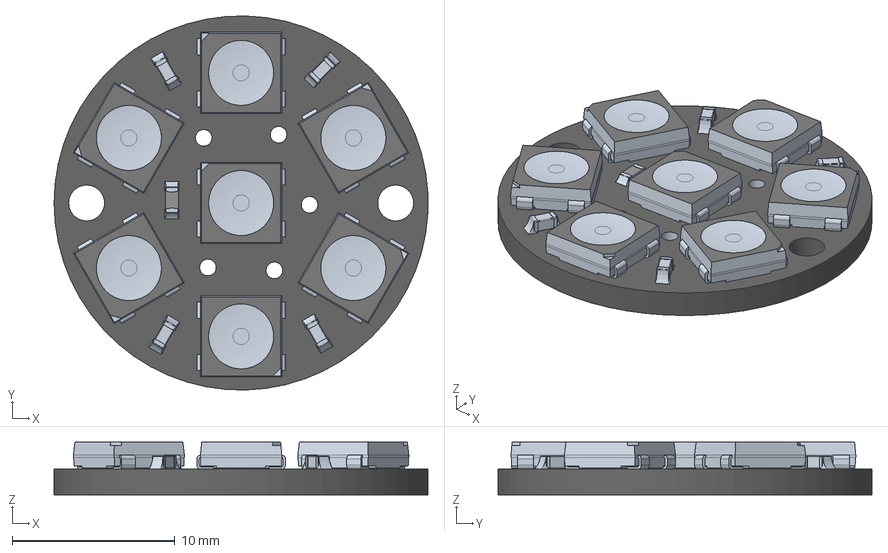
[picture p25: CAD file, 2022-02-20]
SOLIDWORKS/sheikah slate/Neopixel Jewel RGBW.stp
23.0 x 23.0 x 3.24 mm
pcb
leads x 7
processor x 7
lense x 7
C0603 x 4
R0603-NO

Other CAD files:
CAD/PCB Component.SLDASM
CAD/STEMMA_I2C_QTRA.SLDPRT
CAD/AP2112-3.3.SLDPRT
SOLIDWORKS/Left Orange LED Panel.SLDPRT
SOLIDWORKS/Noname_1.SLDPRT
SOLIDWORKS/T93YA.SLDPRT
CAD/1uF.SLDPRT
SOLIDWORKS/TVA1161.SLDPRT
CAD/10uF.SLDPRT
CAD/47K.SLDPRT
CAD/5400 ESP32 Feather V2(2).SLDASM
CAD/5400 ESP32 Feather V2.SLDASM
CAD/Board.SLDPRT
CAD/CP2102N-24.SLDPRT
CAD/DMG3415U.SLDPRT
CAD/DUAL NPN.SLDPRT
CAD/ESP32-PICO-MINI-02MINI.SLDPRT
CAD/JSTPH.SLDPRT
CAD/KMR2.SLDPRT
CAD/MBR540.SLDPRT
CAD/MCP73831T-2ACI_OT.SLDPRT
CAD/NeoPixel Mini Button PCB.SLDPRT
CAD/RED.SLDPRT
CAD/Sheikah Slate Body Bottom usb access.STL
CAD/Sheikah Slate Body Bottom.STL
CAD/USB Type C.SLDPRT
CAD/WS2812B3535.SLDPRT
CAD/board_bare.SLDPRT
CAD/board_bare.step
Old (archive)/Old (archive)/SOLIDWORKS/1-640453-5.SLDPRT
Old (archive)/Old (archive)/SOLIDWORKS/1N5819G.SLDPRT
Old (archive)/Old (archive)/SOLIDWORKS/640453-3.SLDPRT
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

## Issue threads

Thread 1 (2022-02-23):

PCB trace for speaker control is routed incorrectly

emilyanthony4244, 2022-02-23:
The speaker must be wired to the DAC pin on the Adafruit M0 to function correctly. This DAC pin is A0. The trace currently goes to A3.

Short term proposed solution since I already ordered boards: Cut the trace from A3 to C6. Route a wire ~24GA on the bottom of the board from A0 to the - pin on C6.

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

Closed 2023-08-14.

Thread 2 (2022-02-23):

Schematic errors

emilyanthony4244, 2022-02-23:
PA18 goes to pin 4 of J3 on the schematic. It needs to go to pin 3 instead. The board traces are correct, this is just inconsistent with the schematic. PA18 also should not attach to pin 3 of J4. The board traces are correct, this is just inconsistent with the schematic.
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

AIN3 to C6 should be changed to AIN0 to C6.
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
Relates to https://github.com/emilyanthony4244/Sheikah_Slate/issues/1

Closed 2023-08-14.

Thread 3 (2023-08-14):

Touch Input Pins from RA8875 are unconnected

emilyanthony4244, 2023-08-14:
Pins 12-15 from the RA8875 breakout are unconnected. This may cause issues if I manage to get TFT_eSPI library to work with the RA8875.

Workaround:

Run trace wires between:
Pin 12 RA8875 breakout to A3
Pin 13 RA8875 breakout to D32
Pin 14 RA8875 breakout to D14
Pin 15 RA8875 breakout to SW38

In slate config, define the adatouch pins as follows:

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

emilyanthony4244, 2023-08-18:
Resolved with board redesign

Closed 2023-08-18.

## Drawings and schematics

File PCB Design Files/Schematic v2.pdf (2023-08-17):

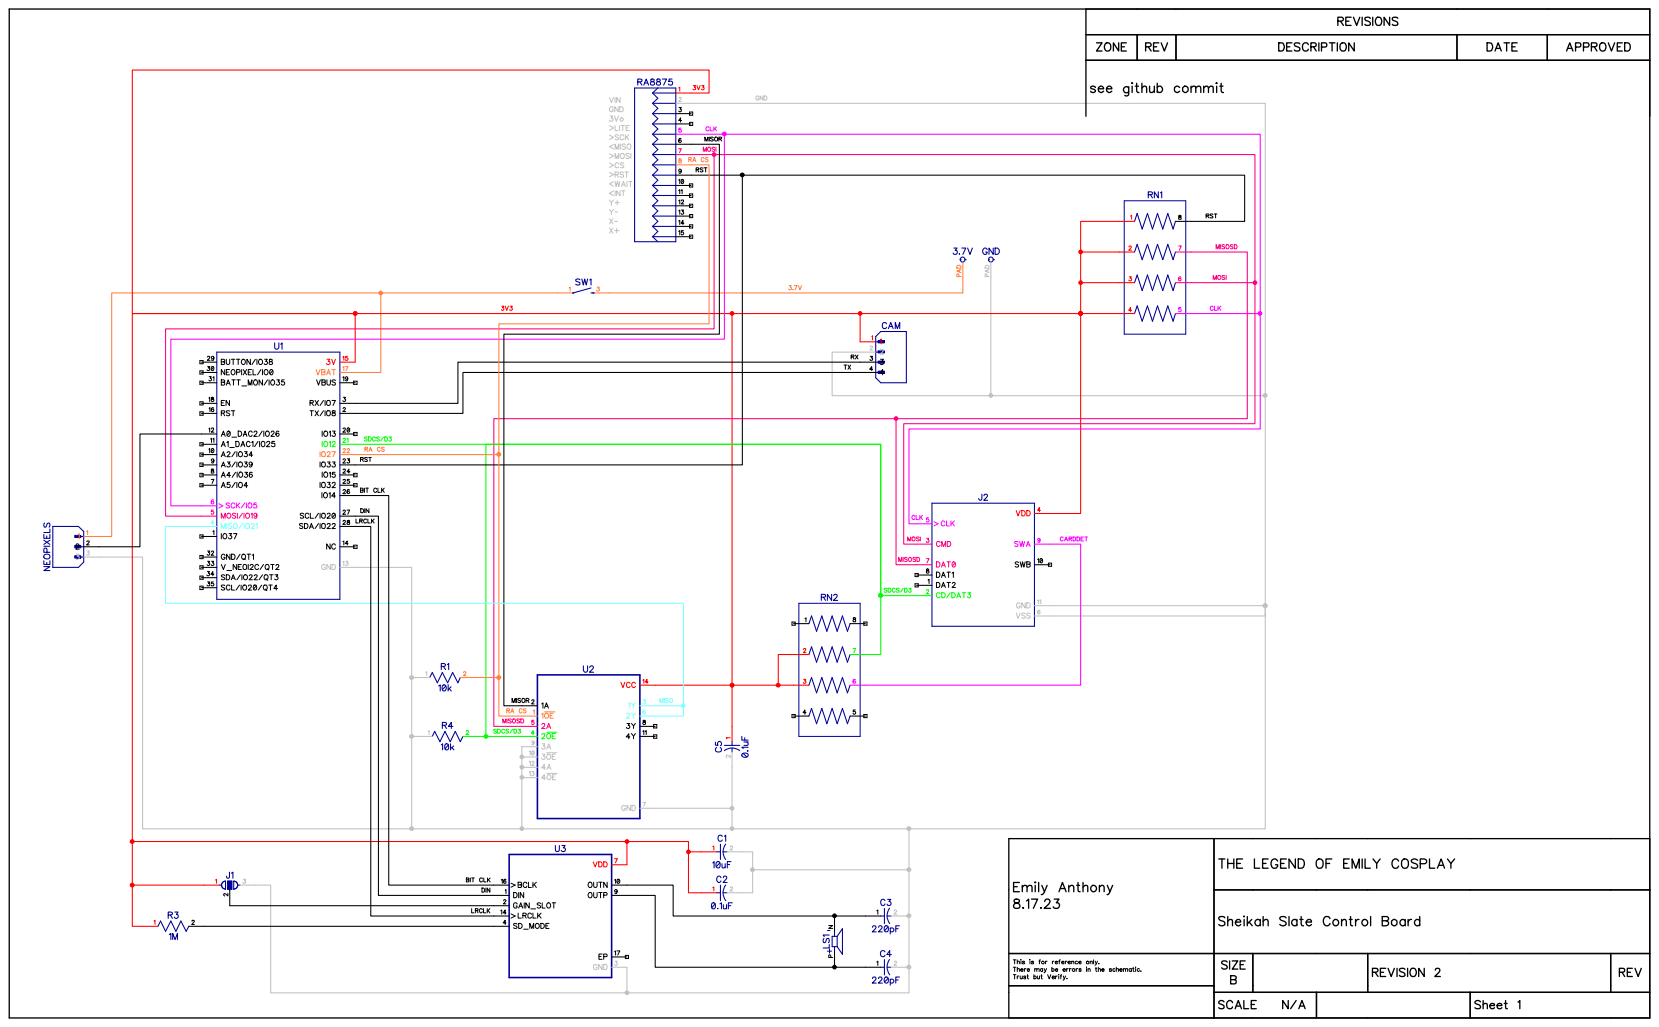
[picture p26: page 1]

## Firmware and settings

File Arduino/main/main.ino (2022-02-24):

//included libraries
#include <BufferedPrint.h>
#include <FreeStack.h>
#include <MinimumSerial.h>
#include <RingBuf.h>
#include <SdFat.h>
#include <SdFatConfig.h>
#include <sdios.h>
//#include <SD.h>
#include <SPI.h>
SdFat SD;
#include <SamdAudio.h> //https://github.com/AloyseTech/SamdAudio
#include <Adafruit_NeoPixel.h>
#include <Adafruit_GFX.h>    // Core graphics library
#include <Wire.h>
#include "Adafruit_RA8875.h"
#include <Adafruit_STMPE610.h>
#include <Adafruit_VC0706.h>

//camera
#define cameraconnection Serial1
Adafruit_VC0706 cam = Adafruit_VC0706(&cameraconnection);

//neopixel global variables
#define LED_PIN         10          //D10
#define LED_COUNT       23          // 16 on ring + 7 on jewel = 23
#define DELAYVAL        100         // Time (in milliseconds) to pause between pixels, dropped from 500 from adafruit examples//RGB values for orange and blue LEDS  
Adafruit_NeoPixel strip(LED_COUNT, LED_PIN, NEO_GRB + NEO_KHZ800);
uint32_t orange = strip.Color(117, 62, 26);
uint32_t blue = strip.Color(26, 117, 116);

//screen global variables
#define RA8875_INT 9
#define RA8875_CS A5
#define RA8875_RESET A4
#define BUFFPIXEL 100     //this is bumped from 20 from the Adafruit examples. The M0 has way more RAM (32K) vs the Uno's ATmega328P (2K), but we're doing a lot of thinking here. TBD on final number
Adafruit_RA8875 tft = Adafruit_RA8875(RA8875_CS, RA8875_RESET);


// SD chip select pin
#define YOUR_SD_CS 4

//speaker global variables
#define NUM_AUDIO_CHANNELS 1                //could be 1,2 or 4 for sound
#define AUDIO_BUFFER_SIZE 1024              //512 works fine for 22.05kh, set buffer size to 1024 for 32khz and 44.1khz for Adafruit M0 with QUAD Flash

const unsigned int sampleRate = 22050;      //hz. indicate sample rate here (use audacity to convert your wav)

//included wav files
const char *chirp = "chirp.wav"; //sheikah sensor chirp
const char *wakeup = "wakeup.wav"; //sound on wakeup

//speaker
SamdAudio AudioPlayer;

//Function prototypes
void neopixelsOn();
void neopixelsBreathe();
void noise(const char wavname);
void bmpDraw(const char *filename, int x, int y);



void setup() {
  // put your setup code here, to run once:

//Pinmodes
  pinMode(10, OUTPUT); //neopixels
  pinMode(9, INPUT); //RA8875 interrupt pin
  pinMode(0, OUTPUT); //DAC for speaker
  pinMode(A4, OUTPUT); //RA8875 RST
  pinMode(A5, OUTPUT); //RA8875 CS

//neopixels
  strip.begin();
  strip.show(); // Initialize all pixels to 'off'

//Initialize serial for startup
  Serial.begin(9600);
  if (!SD.begin(YOUR_SD_CS))
  {
    Serial.println("initialization failed!");
    return;
  }

  Serial.println("initialization done.");  Serial.println("RA8875 start");

  /* Initialize the display using 'RA8875_480x80', 'RA8875_480x128', 'RA8875_480x272' or 'RA8875_800x480' */
  if (!tft.begin(RA8875_800x480)) {
    Serial.println("RA8875 Not Found!");
    while (1);
  }

  Serial.println("Found RA8875");

  tft.displayOn(true);
  tft.GPIOX(true);      // Enable TFT - display enable tied to GPIOX
  tft.PWM1config(true, RA8875_PWM_CLK_DIV1024); // PWM output for backlight
  tft.PWM1out(255);

  Serial.print("(");   Serial.print(tft.width());   Serial.print(", ");   Serial.print(tft.height());   Serial.println(")");
  tft.graphicsMode();                 // go back to graphics mode
  tft.fillScreen(RA8875_BLACK);
  tft.graphicsMode();

// Try to locate the camera
  Serial.println("VC0706 Camera snapshot test");
  if (cam.begin()) {
    Serial.println("Camera Found:");
  } else {
    Serial.println("No camera found?");
    return;
  }

// Print out the camera version information (optional)
  char *reply = cam.getVersion();
  if (reply == 0) {
    Serial.print("Failed to get version");
  } else {
    Serial.println("-----------------");     Serial.print(reply);     Serial.println("-----------------");
  }

    cam.setImageSize(VC0706_640x480);        

//audio startup
  Serial.print("Initializing Audio Player...");
    AudioPlayer.begin(sampleRate);
      Serial.println(" done.");
  AudioPlayer.play(wakeup, 1); // play wakeup tone
}

void loop() {
  // put your main code here, to run repeatedly:

  neopixelsOn();
  bmpDraw("shiekahsymbol.bmp", 0, 0);

}

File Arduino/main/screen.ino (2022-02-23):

// screen functions

void bmpDraw(const char *filename, int x, int y) {
  File     bmpFile;
  int      bmpWidth, bmpHeight;   // W+H in pixels
  uint8_t  bmpDepth;              // Bit depth (currently must be 24)
  uint32_t bmpImageoffset;        // Start of image data in file
  uint32_t rowSize;               // Not always = bmpWidth; may have padding
  uint8_t  sdbuffer[3*BUFFPIXEL]; // pixel in buffer (R+G+B per pixel)
  uint16_t lcdbuffer[BUFFPIXEL];  // pixel out buffer (16-bit per pixel)
  uint8_t  buffidx = sizeof(sdbuffer); // Current position in sdbuffer
  boolean  goodBmp = false;       // Set to true on valid header parse
  boolean  flip    = true;        // BMP is stored bottom-to-top
  int      w, h, row, col;
  uint8_t  r, g, b;
  uint32_t pos = 0, startTime = millis();
  uint8_t  lcdidx = 0;
  boolean  first = true;


  if((x >= tft.width()) || (y >= tft.height())) return;

  Serial.println();
  Serial.print(F("Loading image '"));   Serial.print(filename);   Serial.println('\'');

  // Open requested file on SD card
  if ((bmpFile = SD.open(filename)) == false) {
    Serial.println(F("File not found"));
    return;
  }

  // Parse BMP header
  if(read16(bmpFile) == 0x4D42) { // BMP signature
    Serial.println(F("File size: "));
    Serial.println(read32(bmpFile));
    (void)read32(bmpFile); // Read & ignore creator bytes
    bmpImageoffset = read32(bmpFile); // Start of image data
    Serial.print(F("Image Offset: "));
    Serial.println(bmpImageoffset, DEC);

    // Read DIB header
    Serial.print(F("Header size: "));
    Serial.println(read32(bmpFile));
    bmpWidth  = read32(bmpFile);
    bmpHeight = read32(bmpFile);

    if(read16(bmpFile) == 1) { // # planes -- must be '1'
      bmpDepth = read16(bmpFile); // bits per pixel
      Serial.print(F("Bit Depth: "));
      Serial.println(bmpDepth);
      if((bmpDepth == 24) && (read32(bmpFile) == 0)) { // 0 = uncompressed
        goodBmp = true; // Supported BMP format -- proceed!
        Serial.print(F("Image size: "));
        Serial.print(bmpWidth);
        Serial.print('x');
        Serial.println(bmpHeight);

        // BMP rows are padded (if needed) to 4-byte boundary
        rowSize = (bmpWidth * 3 + 3) & ~3;

        // If bmpHeight is negative, image is in top-down order.
        // This is not canon but has been observed in the wild.
        if(bmpHeight < 0) {
          bmpHeight = -bmpHeight;
          flip      = false;
        }

        // Crop area to be loaded
        w = bmpWidth;
        h = bmpHeight;
        if((x+w-1) >= tft.width())  w = tft.width()  - x;
        if((y+h-1) >= tft.height()) h = tft.height() - y;

        // Set TFT address window to clipped image bounds

        for (row=0; row<h; row++) { // For each scanline...
          // Seek to start of scan line.  It might seem labor-
          // intensive to be doing this on every line, but this
          // method covers a lot of gritty details like cropping
          // and scanline padding.  Also, the seek only takes
          // place if the file position actually needs to change
          // (avoids a lot of cluster math in SD library).
          if(flip) // Bitmap is stored bottom-to-top order (normal BMP)
            pos = bmpImageoffset + (bmpHeight - 1 - row) * rowSize;
          else     // Bitmap is stored top-to-bottom
          pos = bmpImageoffset + row * rowSize;
          if(bmpFile.position() != pos) { // Need seek?
            bmpFile.seek(pos);
            buffidx = sizeof(sdbuffer); // Force buffer reload
          }

          for (col=0; col<w; col++) { // For each column...
            // Time to read more pixel data?
            if (buffidx >= sizeof(sdbuffer)) { // Indeed
              // Push LCD buffer to the display first
              if(lcdidx > 0) {
                tft.drawPixel(col+x, row+y, lcdbuffer[lcdidx]);
                lcdidx = 0;
                first  = false;
              }

              bmpFile.read(sdbuffer, sizeof(sdbuffer));
              buffidx = 0; // Set index to beginning
            }

            // Convert pixel from BMP to TFT format
            b = sdbuffer[buffidx++];
            g = sdbuffer[buffidx++];
            r = sdbuffer[buffidx++];
            lcdbuffer[lcdidx] = color565(r,g,b);
            tft.drawPixel(col+x, row+y, lcdbuffer[lcdidx]);
          } // end pixel

        } // end scanline

        // Write any remaining data to LCD
        if(lcdidx > 0) {
          tft.drawPixel(col+x, row+y, lcdbuffer[lcdidx]);
        }

        Serial.print(F("Loaded in "));
        Serial.print(millis() - startTime);
        Serial.println(" ms");

      } // end goodBmp
    }
  }

  bmpFile.close();
  if(!goodBmp) Serial.println(F("BMP format not recognized."));

}

uint16_t read16(File f) {
  uint16_t result;
  ((uint8_t *)&result)[0] = f.read(); // LSB
  ((uint8_t *)&result)[1] = f.read(); // MSB
  return result;
}

uint32_t read32(File f) {
  uint32_t result;
  ((uint8_t *)&result)[0] = f.read(); // LSB
  ((uint8_t *)&result)[1] = f.read();
  ((uint8_t *)&result)[2] = f.read();
  ((uint8_t *)&result)[3] = f.read(); // MSB
  return result;
}

uint16_t color565(uint8_t r, uint8_t g, uint8_t b) {
  return ((r & 0xF8) << 8) | ((g & 0xFC) << 3) | (b >> 3);
}

byte decToBcd(byte val){
  // Convert normal decimal numbers to binary coded decimal
  return ( (val/10*16) + (val%10) );
}

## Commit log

2022-02-20 File structure, gerbers
    [1 - Top.gbr, 2 - Bottom.gbr, BoardOutline.gbr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]
2022-02-20 File structure fix
    [1 - Top.gbr, 2 - Bottom.gbr, BoardOutline.gbr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]
2022-02-20 Add SOLIDWORKS folder
    [1-640453-5.SLDPRT, 1N5819G.SLDPRT, 640453-3.SLDPRT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]
2022-02-20 Push 2.20.2022
    Added BOM.csv for breakdown of materials required to build this
    Added readme.md with content
    [BOM.csv, slate BOM pcb.csv]
2022-02-20 MCB updates
    Added MCB readme, rearranged some files, added render images
    [1 - Top.gbr, 2 - Bottom.gbr, BoardOutline.gbr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]
2022-02-20 update mcb readme
    apparently image urls are case sensitive
2022-02-20 Added 3D printing STLs
    Sculpted and unsculpted variants for body pieces
    [Back Body Sculpted.stl, sheikah slate swirly bits.SLDPRT]
2022-02-21 Added schematic
    [sheikah slate swirly bits.SLDPRT]
2022-02-24 add arduino libraries and camera snapshot
2022-03-10 Create pick and place.csv
    [pick and place.csv]
2022-09-21 Github cleanup to make way for v2
    Archive, prep for V2
    [1-640453-5.SLDPRT, 1N5819G.SLDPRT, 640453-3.SLDPRT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]
2023-08-10 making way for v2
    [1 - Top.gbr, 2 - Bottom.gbr, BoardOutline.gbr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]
2023-08-10 Delete cutting block.STL
    should not be here
    [cutting block.STL]
2023-08-10 Create slatev2.dip
    converted diptrace file from gerbers, lacks contextual data from schematic. need to redraw
2023-08-10 update geometry to v2
    [10uF.SLDPRT, 1uF.SLDPRT, 47K.SLDPRT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]
2023-08-10 cleanup
    folders are hard
    [10uF.SLDPRT, 1uF.SLDPRT, 47K.SLDPRT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]
2023-08-12 pcb files upload
    [1 - Top.gbr, 2 - Bottom.gbr, BoardOutline.gbr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]
2023-08-15 framework for v2.0 arduino and update to readme
2023-08-15 arduino stuff
2023-08-16 cad fixes
    [1-640453-5.SLDPRT, 1N5819G.SLDPRT, 640453-3.SLDPRT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]
2023-08-17 Update PCB Design to V2.0
    Deleted SDIO Support
    Added SD SPI to 74HC125 circuit
    Deleted larger speaker breakout
    Deleted DIP Switch
    Moved LRCLK of speaker circuit to GPIO22
    Moved SDCS to GPIO12
    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
2023-08-17 Connect RST pin, update readme
    [BOM v2.csv]
2023-08-17 add readable schematics
2023-08-22 fix gerbers
    nc drill missing
